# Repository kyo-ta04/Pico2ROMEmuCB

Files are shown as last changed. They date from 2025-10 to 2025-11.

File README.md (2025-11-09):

# Pico2ROMEmu - RP2350B Core Board Version
<!-- ![Pico2ROMEmu RP2350B Core Board](./IMG/Pico2ROMEmuPCB_CoreBoard_img_1.jpg) -->
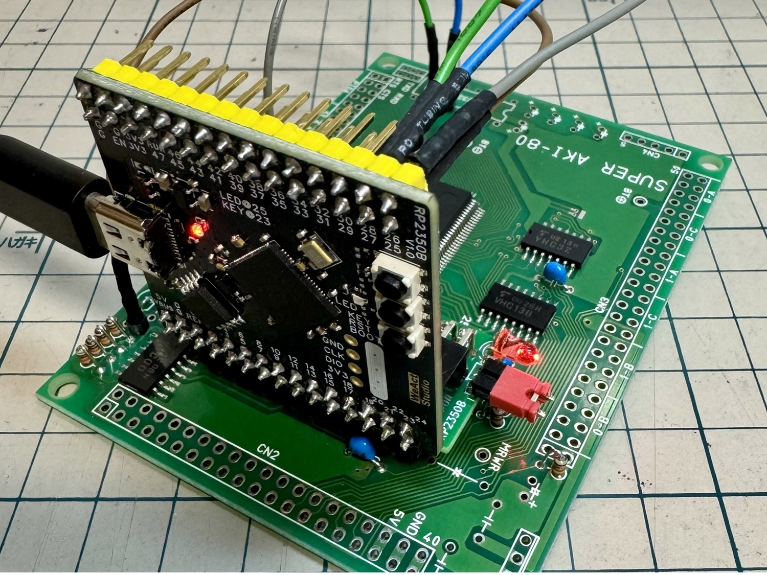
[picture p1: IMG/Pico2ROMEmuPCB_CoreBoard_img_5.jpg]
Pico2ROMEmu RP2350B Core Board

このプロジェクトは Pico2ROMEmuに RP2350B Core Boardを使用した簡単で高速なROMエミュレータです  
[English Readme](./README.en.md)

## 特徴
- 詳しくは[Pico2ROMEmu](https://github.com/kyo-ta04/Pico2ROMEmuBR)をご覧ください。

## 構成
- KiCad 回路図、PCB、ガーバーファイルはこちら→ [./PCB/](./PCB/) (**2025/11/09 追加 V1.0 R0.1**)
  - KiCad Ver9.0.6、 JLCPCB Fabrication Toolkit Plugin 使用
- `saki80mon041_const.c` などの ROMデータ部分は [https://github.com/yyhayami/saki80mon041](https://github.com/yyhayami/saki80mon041) 由来です。  
UNIMON for SAKI80は、asano氏が公開されているUniversal MonitorをベースにAki.H氏による大幅な拡張がなされてEMUZ80用に公開されているEMUZ80_Monitor Rev.B04を @yyhayami氏が Super AKI-80 で動作するよう移植したものです。
- `rom_basic_const.c` などの ROM-BASIC 部分は [saki80basic](https://github.com/vintagechips/saki80basic) 由来です。
  - 元の[BASICサブセット](http://searle.x10host.com/cpm/index.html)は Grant Searle さんが作成したものであり、[Super AKI-80用に @vintagechip（電脳伝説）](https://vintagechips.wordpress.com/2025/04/24/saki80basic/)さんが移植・改良されています。
- [Tom's SBC](https://oshwlab.com/peabody1929/CPM_Z80_Board_REV_B_copy-76313012f79945d3b8b9d3047368abf7)はpeabody1929さんが作成したものであり、ROMデータは[CP/M machine - Grant Searle](http://searle.x10host.com/cpm/index.html) 由来です。
- [68k-nano](https://github.com/74hc595/68k-nano)は Matt Sarnoff(74hc595)さんが作成、公開されています。 ROMデータはソースから生成しました。
- RP2350 PIO ROMエミュレーション部分は @tendai22plus さんの [ROMエミュレーション](https://github.com/tendai22/emuz80_pico2/blob/main/doc/ROM_EMULATION.md) を参考にさせていただいてます。　参考: [emuz80_pico2](https://github.com/tendai22/emuz80_pico2) 
- 使用している WeAct StudioのRP2350B Core Boardは、Raspberry Pi RP2350Bマイクロコントローラを搭載したコンパクトな開発ボードで、サイズわずか41.4×41.1mmながら全48本のI/Oピンを2つの30ピンヘッダー引き出しています。  
Github : [WeActStudio.RP2350BCoreBoard](https://github.com/WeActStudio/WeActStudio.RP2350BCoreBoard)

## 回路図・資料
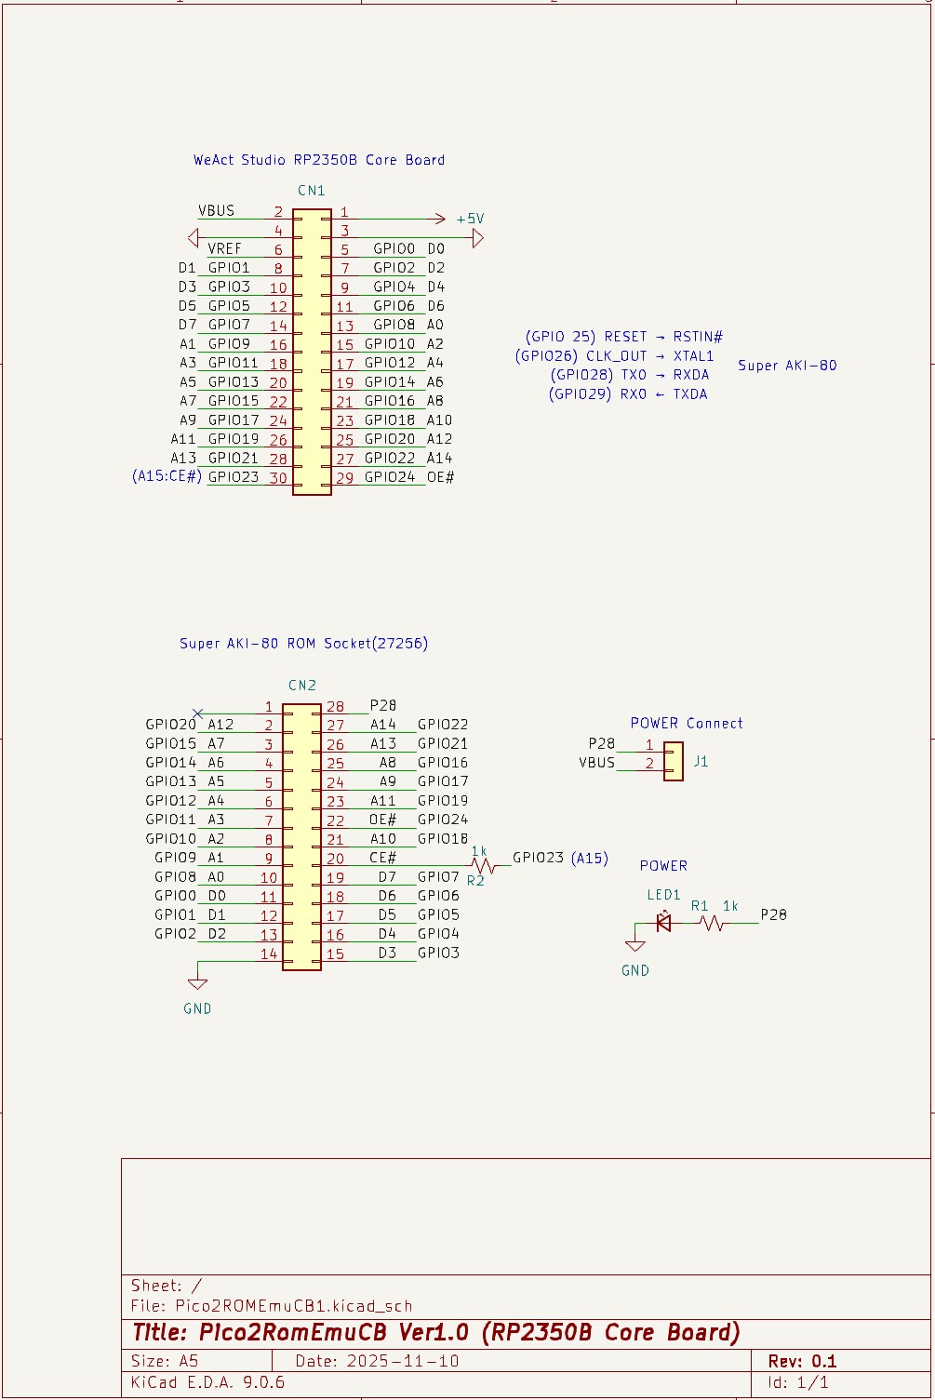
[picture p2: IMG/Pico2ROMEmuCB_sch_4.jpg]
Pico2ROMEmuCB_sch
- 
上記は回路図の画像です。
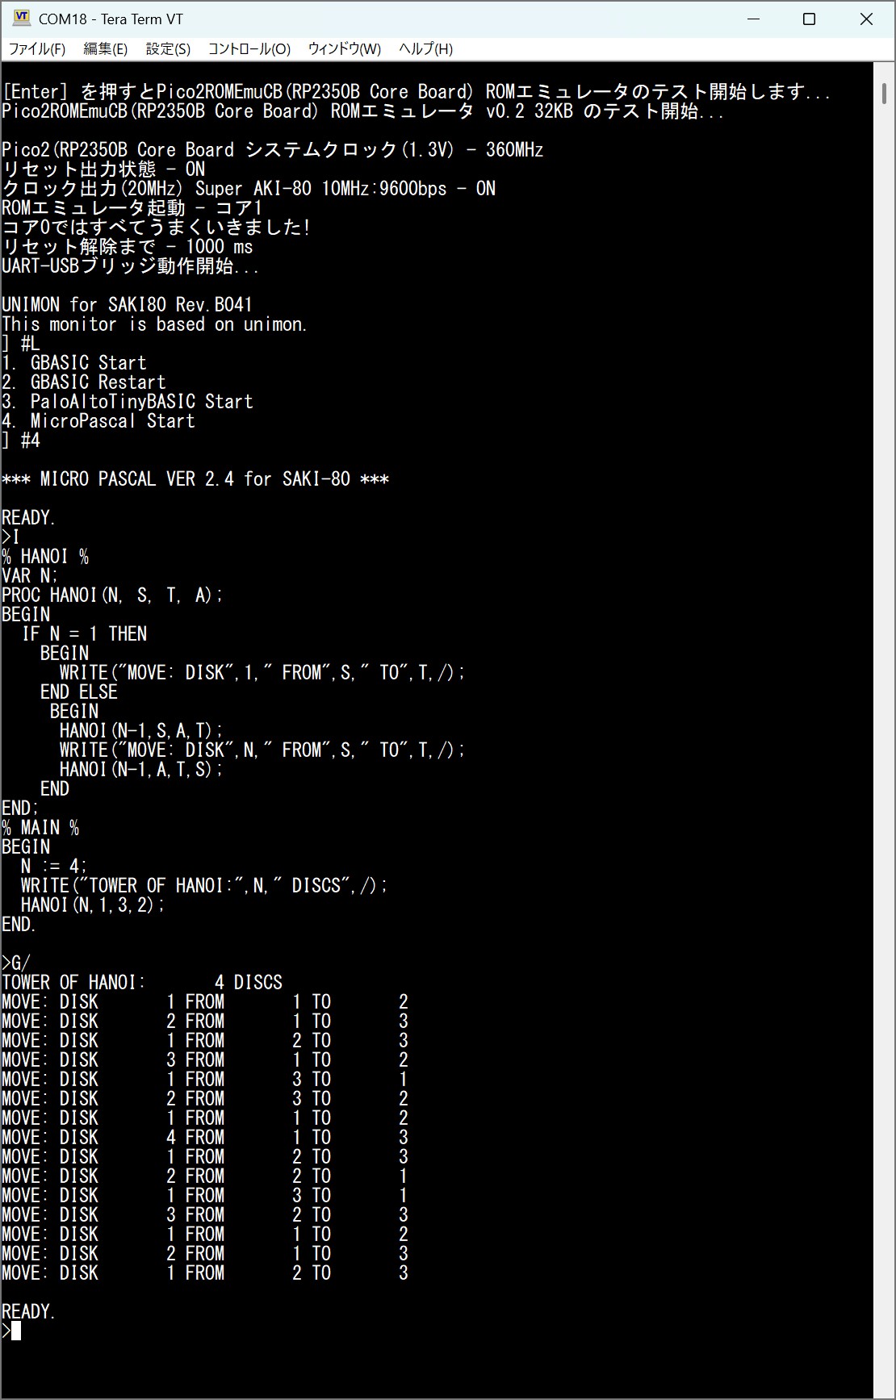
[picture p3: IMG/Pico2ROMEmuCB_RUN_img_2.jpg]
Pico2ROMEmuCB_RUN_img
- 
上記は saki80mon041.hex使用時の実行例画像です。
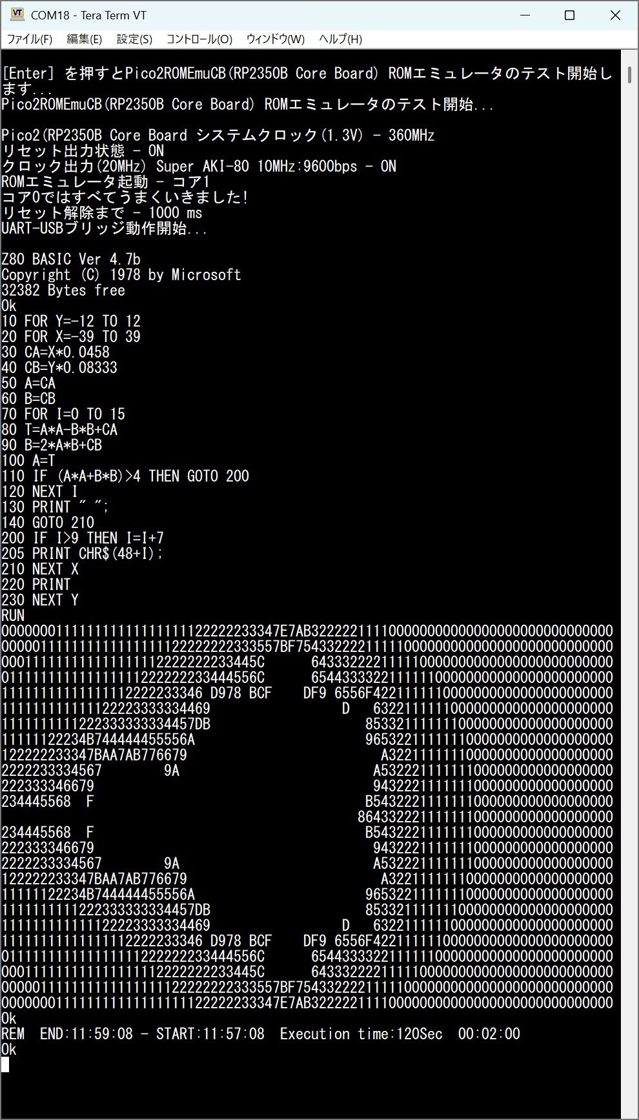
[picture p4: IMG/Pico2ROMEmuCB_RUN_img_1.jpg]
Pico2ROMEmuCB_RUN_img
- 
上記は SAKI80MB.HEX使用時の実行例画像です。

## ライセンス
- 本プロジェクトのソースコードは MIT ライセンスです。
- ROMデータ部分などは元サイトおよび改編元のライセンスを参照してください。

## 免責事項
本ソフトウェアは現状のまま提供されます。いかなる損害についても作者は責任を負いません。

## 謝辞
- Grant Searle さん（[BASICサブセット版/CP/M machine 作者）](http://searle.x10host.com/index.html)）
- @vintagechip さん（[電脳伝説さん Super AKI-80用BASIC 作者](https://vintagechips.wordpress.com/)）
- @tendai22plus さん ([emuz80_pico2  作者](https://github.com/tendai22/emuz80_pico2))
- peabody1929 さん ([Tom's SBC 作者](https://oshwlab.com/peabody1929/works))
- Matt Sarnoff(74hc595)さん ([68k-nano 作者](https://github.com/74hc595/68k-nano))
- @yyhayamiさん（[saki80mon041 作者）](https://github.com/yyhayami/saki80mon041)）
- @electrelic(asano)さん（[Universal Monitor 作者）](https://electrelic.com/electrelic/node/1317)）
- @akih_san(Aki.h) さん（[EMUZ80-MON 作者](https://github.com/akih-san/EMUZ80-MON)）
- @shippoiincho さん、 @kondo_pc88 さん、 @TororoLab さん、 @I_HaL さん、 @antarcticlion さん、 @GAPUX さん、 @Tanuki_Bayashin さん、 @applesorce さん、@W88DodPECuThLOl さんを始めとしたアドバイス、イイね、RPしていただいた皆様。
- Raspberry Pi Pico SDK 開発者の皆様
- 本プロジェクトに関わる全ての方々
- [Pico2ROMEmu](https://github.com/kyo-ta04/Pico2ROMEmuBR)もご覧ください。

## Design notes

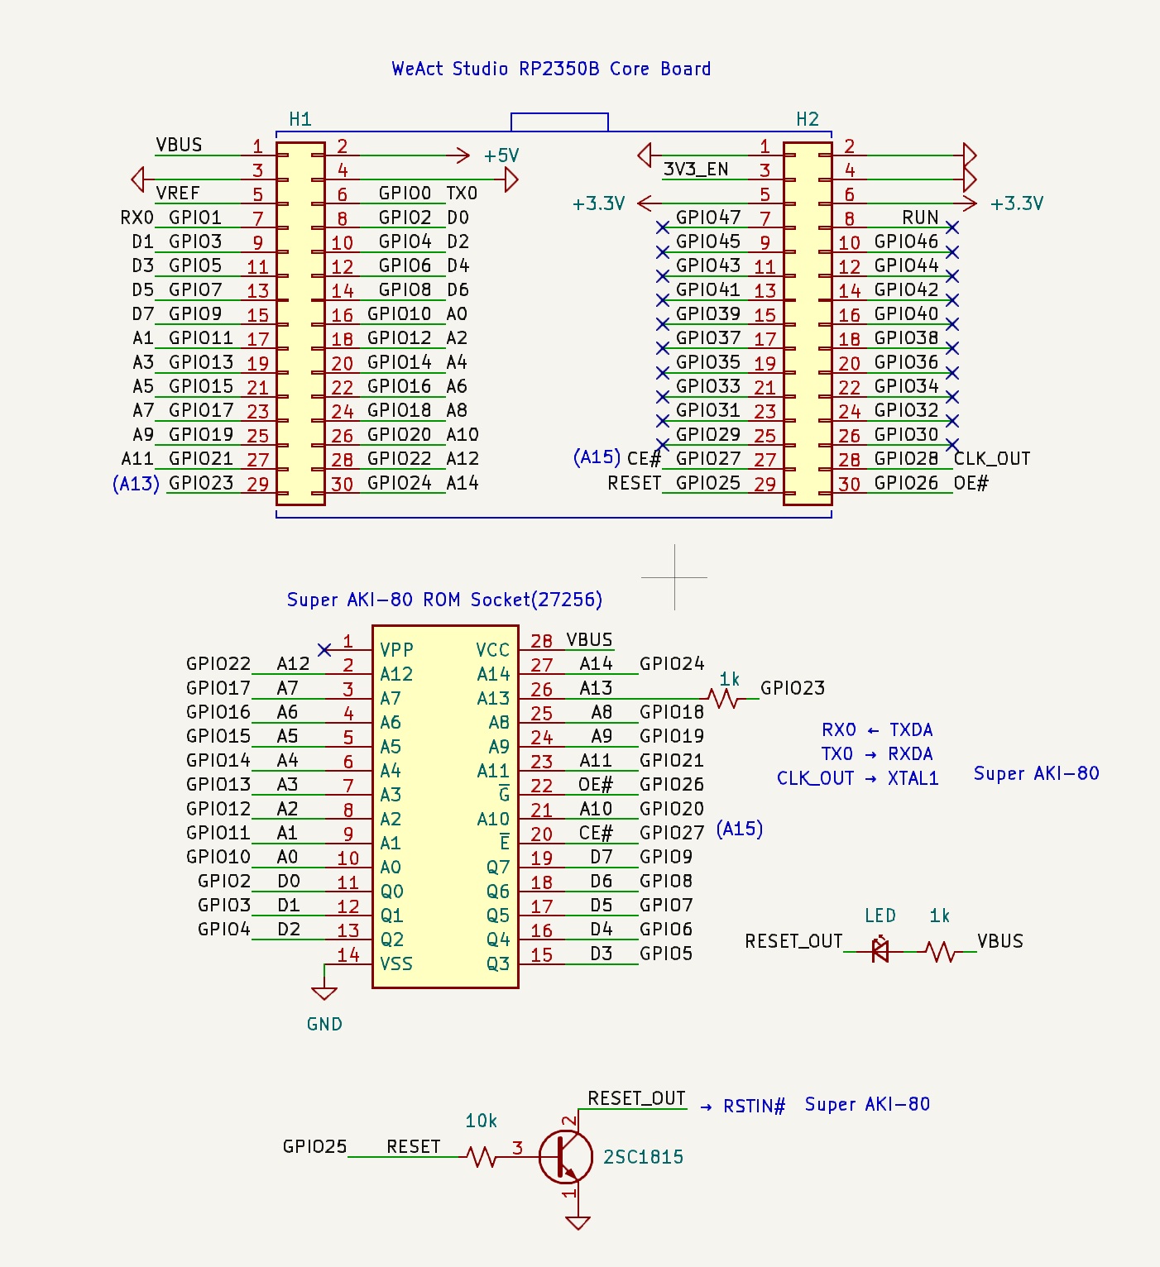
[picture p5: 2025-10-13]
IMG/Pico2ROMEmuCB_sch_2.jpg

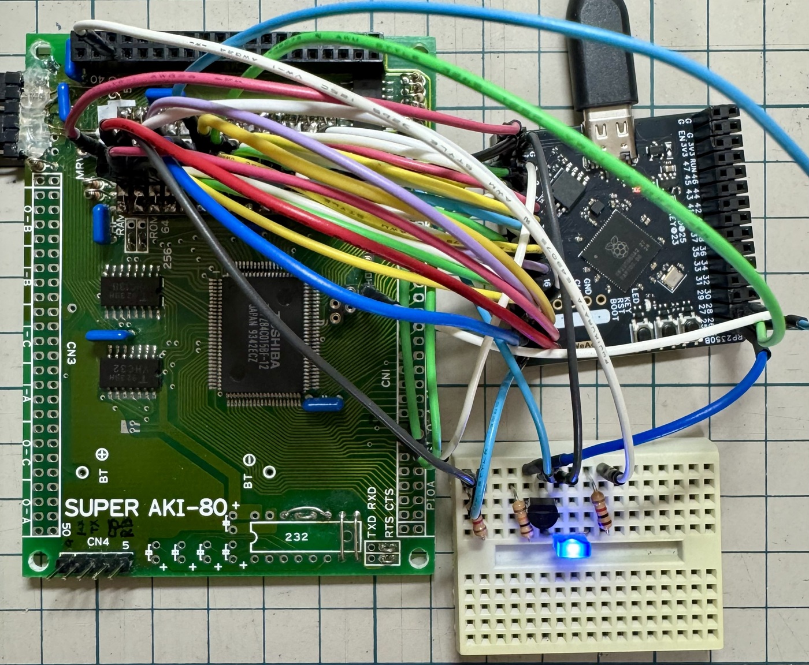
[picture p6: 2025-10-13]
IMG/Pico2ROMEmuPCB_CoreBoard_img_2.jpg

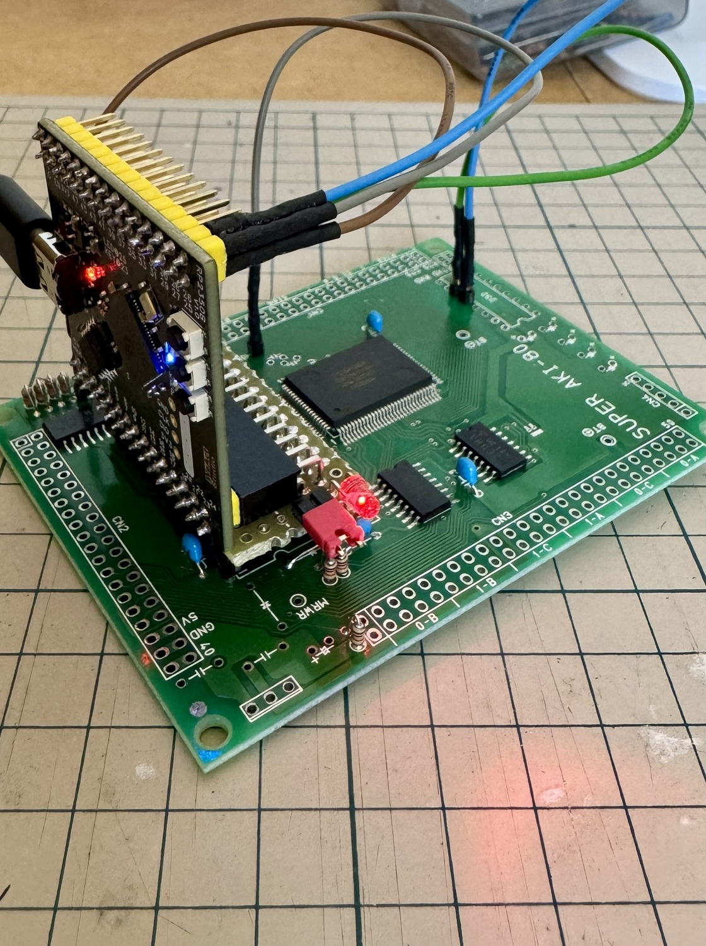
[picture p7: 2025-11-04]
IMG/Pico2ROMEmuPCB_CoreBoard_img_4.jpg

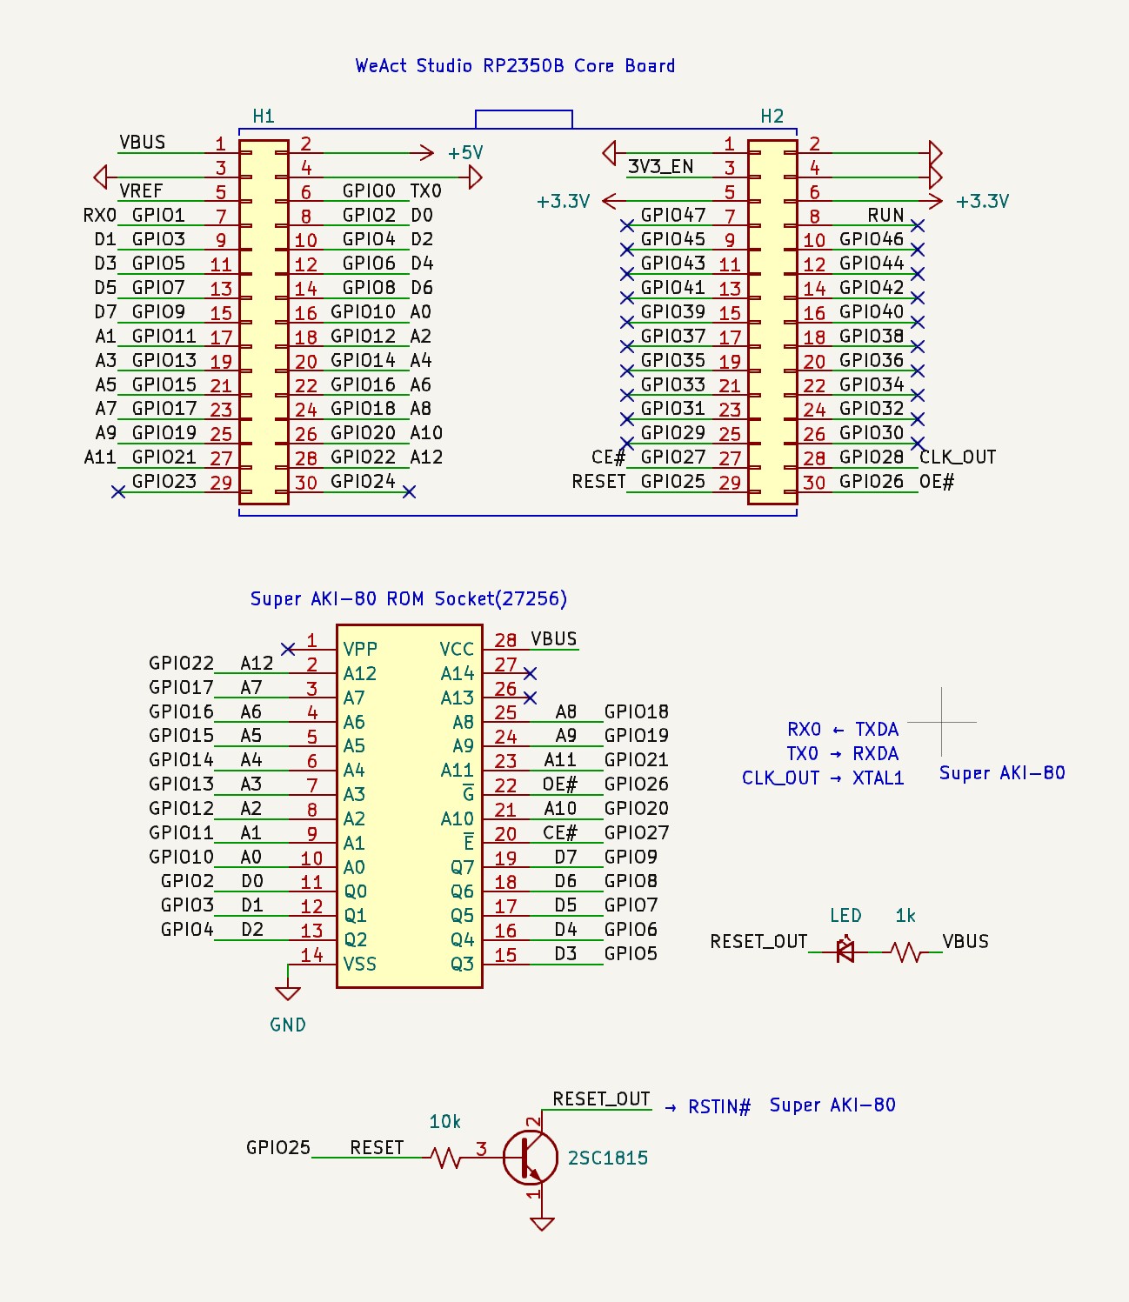
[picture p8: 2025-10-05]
IMG/Pico2ROMEmuCB_sch.jpg

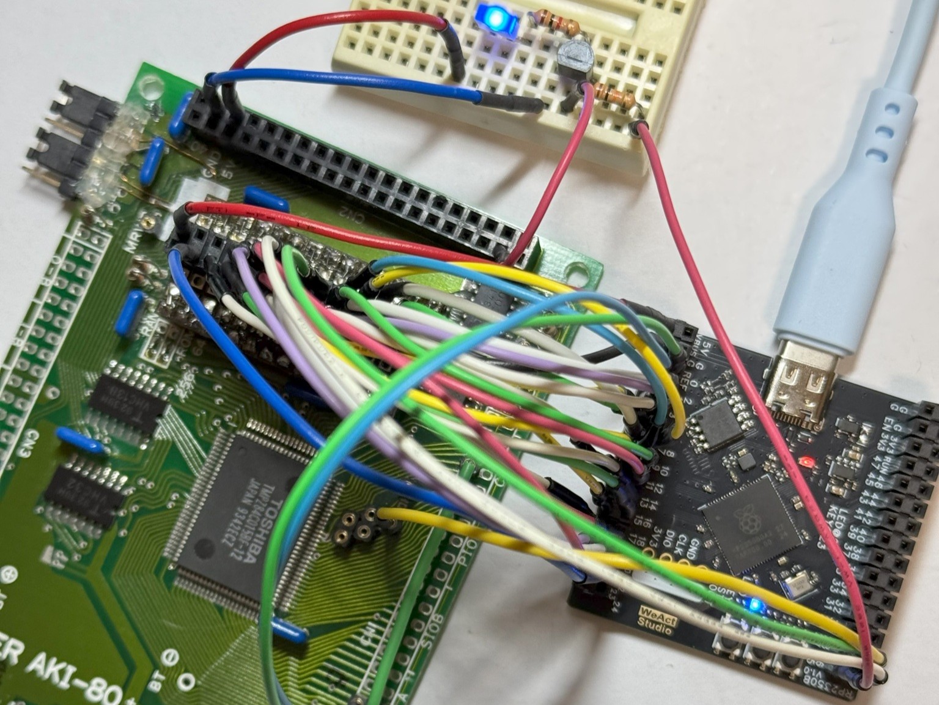
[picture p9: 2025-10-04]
IMG/Pico2ROMEmuPCB_CoreBoard_img_1.jpg

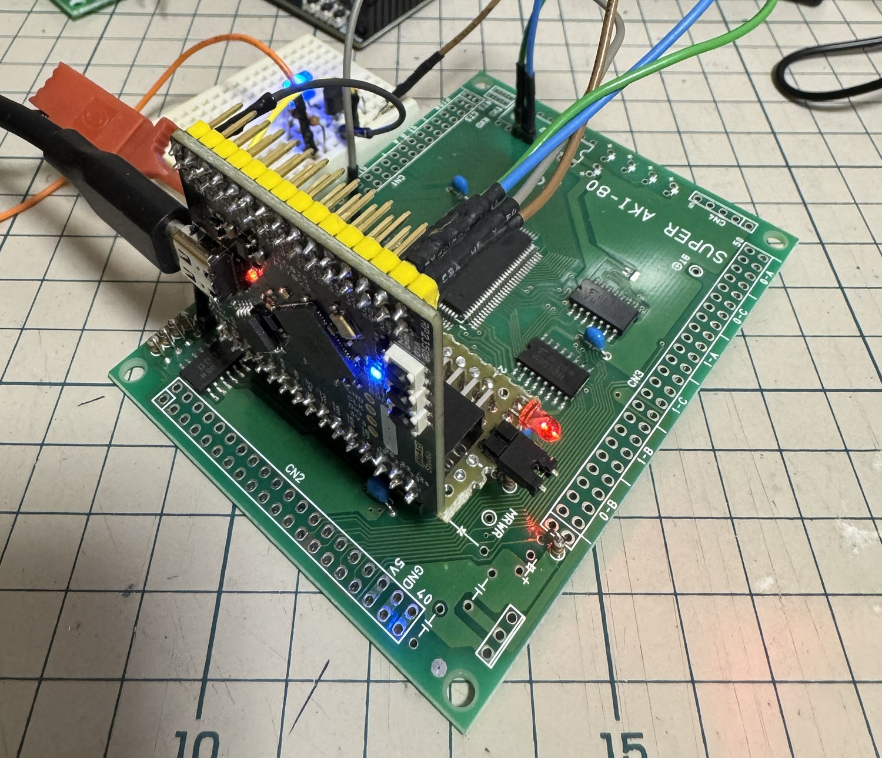
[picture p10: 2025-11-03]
IMG/Pico2ROMEmuPCB_CoreBoard_img_3.jpg

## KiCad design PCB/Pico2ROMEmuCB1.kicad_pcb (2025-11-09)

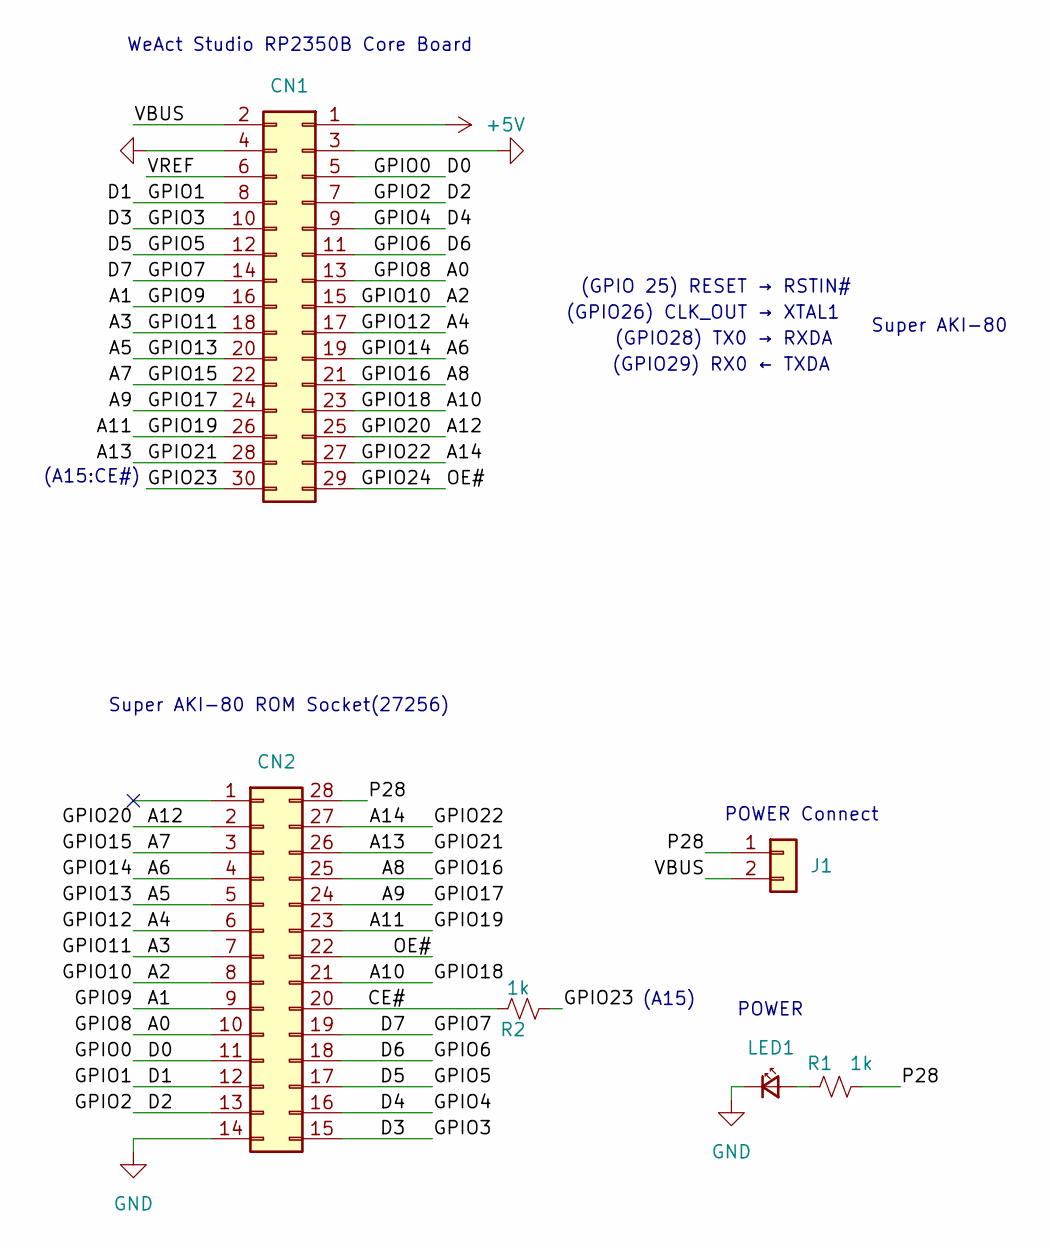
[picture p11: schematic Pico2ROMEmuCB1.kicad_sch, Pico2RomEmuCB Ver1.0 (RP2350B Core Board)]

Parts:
CN1: Conn_02x15; PinSocket_2x15_P2.54mm_Horizontal
CN2: Conn_02x14_Counter_Clockwise; DIP-28_W15.24mm_Socket
J1: Conn_01x02; PinHeader_1x02_P2.54mm_Vertical
LED1: LED_Small; LED_D3.0mm
R1, R2: 1k; R_Axial_DIN0204_L3.6mm_D1.6mm_P5.08mm_Horizontal

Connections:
+5V: CN1.1
/A0: CN1.13, CN2.10
/A1: CN1.16, CN2.9
/A2: CN1.15, CN2.8
/A3: CN1.18, CN2.7
/A4: CN1.17, CN2.6
/A5: CN1.20, CN2.5
/A6: CN1.19, CN2.4
/A7: CN1.22, CN2.3
/A8: CN1.21, CN2.25
/A9: CN1.24, CN2.24
/A10: CN1.23, CN2.21
/A11: CN1.26, CN2.23
/A12: CN1.25, CN2.2
/A13: CN1.28, CN2.26
/A14: CN1.27, CN2.27
/CE#: CN2.20, R2.2
/D0: CN1.5, CN2.11
/D1: CN1.8, CN2.12
/D2: CN1.7, CN2.13
/D3: CN1.10, CN2.15
/D4: CN1.9, CN2.16
/D5: CN1.12, CN2.17
/D6: CN1.11, CN2.18
/D7: CN1.14, CN2.19
/GPIO23: CN1.30, R2.1
/GPIO24: CN1.29, CN2.22
/P28: CN2.28, J1.1, R1.1
/VBUS: CN1.2, J1.2
/VREF: CN1.6
GND: CN1.3, CN1.4, CN2.14, LED1.1 (K)
unnamed: LED1.2 (A), R1.2

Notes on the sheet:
POWER Connect
Super AKI-80
(GPIO28) TX0 → RXDA
WeAct Studio RP2350B Core Board
Super AKI-80 ROM Socket(27256)
POWER
(A15:CE#)
(GPIO26) CLK_OUT → XTAL1
(GPIO 25) RESET → RSTIN#
(GPIO29) RX0 ← TXDA
(A15)

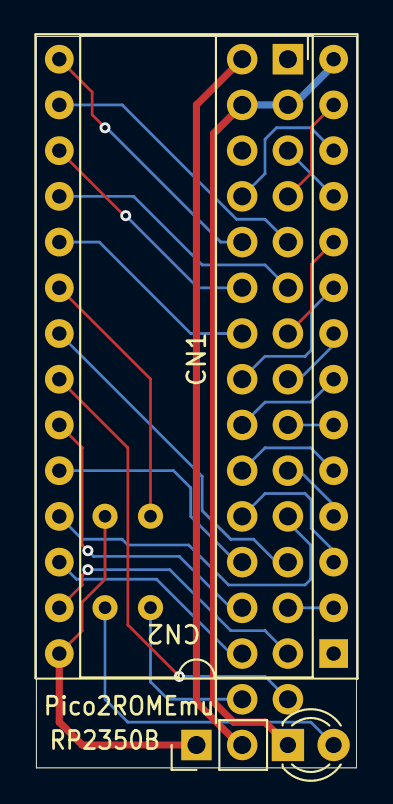
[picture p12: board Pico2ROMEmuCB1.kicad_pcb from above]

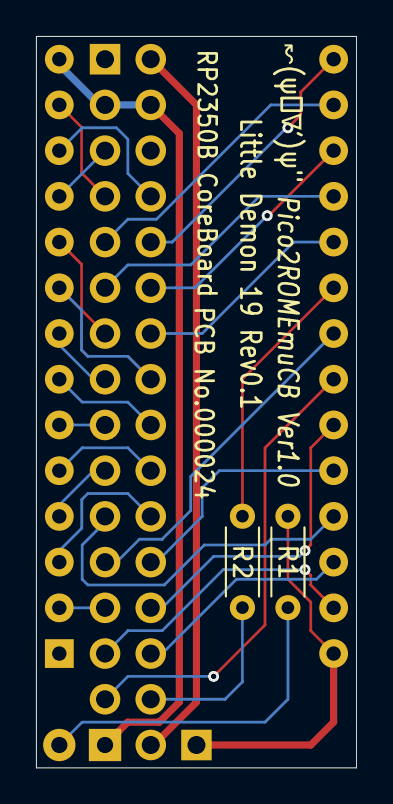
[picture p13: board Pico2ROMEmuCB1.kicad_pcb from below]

Board: 2 copper layers, 17.8 x 40.6 mm, 6 parts (2 on the bottom side), 30 nets.

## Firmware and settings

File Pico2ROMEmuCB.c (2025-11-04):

//
// Pico2ROMEmuCB.c - Pico2ROMEmuCB(RP2350B Core Board) 用 ROMエミュレータ
// 2024/06/15 by @DragonballEZ(kyo-ta04)
//
#include <stdio.h>
#include <string.h>
#include "pico/stdlib.h"
#include "hardware/vreg.h"
#include "hardware/pio.h"
#include "hardware/clocks.h"
#include "hardware/uart.h"
#include "hardware/pll.h"
#include "pico/multicore.h"
#include "rom_emu.pio.h"
// #include "rom_basic_const.c" 
#include "saki80mon041_const.c" 

#define DATA_PINS_BASE 0    // GP0～GP7 (D0-D7 8bit)
#define ADDR_PINS_BASE 8    // GP8～GP22 (A0-A14 15bit)
#define CS_PIN 23           // GP23 Chip Select (CS#:A15)
#define OE_PIN 24           // GP24 Output Enable (OE#)
#define RESETOUT_PIN 25     // GP25 (リセット出力)

#define CLKOUT_PIN 26       // GP26 (クロック出力)

// UART0の設定
#define UART_ID uart0
#define UART_TX_PIN 28
#define UART_RX_PIN 29
#define BAUD_RATE 9600

#define FLAG_VALUE 123

#define ROM_SIZE 32768 // 32Kバイト (15bitアドレス)

// PIO初期化
PIO pio = pio0;
uint sm = 0;


uint8_t rom_data[ROM_SIZE] __attribute__((section(".data")));

// コア1のエントリポイント
// core1_entry()はPIOの状態マシンを実行し、ROMデータを送信する  
__attribute__((noinline)) void __time_critical_func(core1_entry)(void) {
    multicore_fifo_push_blocking(FLAG_VALUE);
    uint32_t g = multicore_fifo_pop_blocking();
    while (true) {
        uint32_t address = pio_sm_get_blocking(pio, sm);    // アドレスを取得
        uint32_t data = rom_data[address];                  // 13bitアドレスに対応
        pio_sm_put(pio, sm, data);                          // データを送信
    }
}


// rom_saki80mon041[]をrom_data[]にコピーする初期化ルーチン
void init_rom_basic_code(void) {
    // rom_saki80mon041[]の内容をrom_data[]の先頭にコピー
    memcpy(rom_data, rom_saki80mon041, sizeof(rom_saki80mon041));
    // 残りのrom_data[]を0xFFで埋める（32Kバイトまで）
    memset(rom_data + sizeof(rom_saki80mon041), 0xFF, ROM_SIZE - sizeof(rom_saki80mon041));
}


// QSPIクロックを調整する関数
void set_qspi_clock_divider(uint32_t sys_clock_khz, uint32_t qspi_max_khz) {
    uint32_t divider = (sys_clock_khz + qspi_max_khz - 1) / qspi_max_khz;
    clock_configure(clk_peri, 0, CLOCKS_CLK_PERI_CTRL_AUXSRC_VALUE_CLKSRC_PLL_SYS, sys_clock_khz * 1000, sys_clock_khz * 1000 / divider);
}

__attribute__((noinline)) int __time_critical_func(main)(void) {
    uint32_t sysclk = 360 * 1000;           // Pico2 システムクロック 280/320/360MHz 
    vreg_set_voltage(VREG_VOLTAGE_1_30);    // 電圧を1.3Vに設定
    sleep_ms(100);                          // 電圧安定のための待機
    set_sys_clock_khz(sysclk, true);        // 高速動作
    set_qspi_clock_divider(sysclk, 133000); // QSPIクロックを133MHz以下に

    stdio_init_all();
    setbuf(stdout, NULL);           // 標準出力のバッファリングを無効化 

    // UART0の初期化
    uart_init(UART_ID, BAUD_RATE);
    // UARTピンの設定（GPIO0=TX, GPIO1=RX）
    gpio_set_function(UART_TX_PIN, GPIO_FUNC_UART);
    gpio_set_function(UART_RX_PIN, GPIO_FUNC_UART);

    // PIO初期化
    uint offset = pio_add_program(pio, &oe_address_control_program);
    pio_sm_config c = oe_address_control_program_get_default_config(offset);

    uint sm1 = 1; // sm1を使用
    uint offset1 = pio_add_program(pio, &clk_out_program);
    pio_sm_config c1 = clk_out_program_get_default_config(offset1);
 
    uint sm2 = 2; // sm2を使用
    // sm2 のリセット出力プログラムをロード
    uint offset2 = pio_add_program(pio, &reset_out_program);
//    pio_sm_config c2 = reset_out_program_get_default_config(offset2);
 
    // GP0-7：出力
    for (int i = 0; i < 8; i++) {
        pio_gpio_init(pio, DATA_PINS_BASE + i);
    }
    // GP8-22：入力(15ピン A0-A14)
    for (int i = 0; i < 15; i++) {
        pio_gpio_init(pio, ADDR_PINS_BASE + i);
    }
    
    pio_gpio_init(pio, RESETOUT_PIN); // リセット出力ピン(GP25)の初期化
    pio_gpio_init(pio, OE_PIN); // OEピン(GP24)の初期化
    pio_gpio_init(pio, CS_PIN); // CSピン(GP23)の初期化
    pio_gpio_init(pio, CLKOUT_PIN); // CLK出力ピン(GP26)の初期化

    sm_config_set_in_pins(&c, ADDR_PINS_BASE);
    sm_config_set_out_pins(&c, DATA_PINS_BASE, 8);
    sm_config_set_jmp_pin(&c, OE_PIN); // GPIO24 OEをJMPピンとして設定
    

    pio_sm_set_consecutive_pindirs(pio, sm, DATA_PINS_BASE, 8, false); // 出力ピン初期化

    // シフトレジスタの設定
    sm_config_set_in_shift(&c, false, false, 0); // ISR（入力シフトレジスタ）のシフト方向
    sm_config_set_out_shift(&c, true, false, 0); // OSR（出力シフトレジスタ）のシフト方向

    // sm1 のクロック出力を設定 
    sm_config_set_set_pins(&c1, CLKOUT_PIN, 1); // GP26をクロック出力ピンとして設定
    pio_sm_set_consecutive_pindirs(pio, sm1, CLKOUT_PIN, 1, true); // CLKOUTピンの初期化

    float clkout_freq = 20000.0f; // kHz - 20MHz (Super Aki-80 10MHz 9600bps)
    sm_config_set_clkdiv(&c1, (float)sysclk / (2.0f * clkout_freq)); // クロック出力のクロック設定

     // sm2 のリセット出力を設定
    // Set initial pin direction to INPUT (false) for Hi-Z state at startup.
    pio_sm_set_consecutive_pindirs(pio, sm2, RESETOUT_PIN, 1, false); // リセット出力ピンの初期化(Hi-z:入力に設定) 
    pio_sm_config c2 = reset_out_program_get_default_config(offset2);
    sm_config_set_set_pins(&c2, RESETOUT_PIN, 1); // GP25をリセット出力ピンとして設定 ??????
    sm_config_set_clkdiv(&c2, sysclk / 10); //  10kHz (リセット出力のクロック)
    pio_sm_init(pio, sm2, offset2, &c2);
    pio_sm_set_enabled(pio, sm2, true);

    // sm のROMエミュプログラムをロード
    pio_sm_init(pio, sm, offset, &c);
    pio_sm_set_enabled(pio, sm, true);

    sleep_ms(1); // 1ms待機

    // sm1 のクロック出力プログラムをロード
    pio_sm_init(pio, sm1, offset1, &c1);
    pio_sm_set_enabled(pio, sm1, true);
    init_rom_basic_code(); // rom_basic_const.cから初期化
    sleep_ms(3000); // 3秒待機
    // [Enter]入力を待つ
    printf("\n[Enter] を押すとPico2ROMEmuCB(RP2350B Core Board) ROMエミュレータのテスト開始します...\n");
    while (true) {
        int c = getchar_timeout_us(100000); // 100msタイムアウト
        if (c == '\r') { // [Enter]（CR）が入力されたら開始
            printf("Pico2ROMEmuCB(RP2350B Core Board) ROMエミュレータ v0.2 32KB のテスト開始...\n");
            break;
        }
    }
    printf("\nPico2(RP2350B Core Board) システムクロック(1.3V) - %dMHz\n", sysclk / 1000);
    printf("リセット出力状態 - ON\n");
    printf("クロック出力(%dMHz) Super AKI-80 %dMHz:%dbps - ON\n", (int)(clkout_freq / 1000),(int)(clkout_freq / 2000), BAUD_RATE);
    printf("ROMエミュレータ起動 - コア1\n");
    multicore_launch_core1(core1_entry);
    uint32_t g = multicore_fifo_pop_blocking();
    if (g != FLAG_VALUE)
        printf("うーん、コア0では正しくありません!\n");
    else {
        multicore_fifo_push_blocking(FLAG_VALUE);
        printf("コア0ではすべてうまくいきました!\n");
    }

    uint32_t tim = 1000; 
    printf("リセット解除まで - %d ms\n", tim);
    pio_sm_put(pio, sm2, tim);

    // メインループ
    printf("UART-USBブリッジ動作開始...\n");

    while (true) {
        // UARTの受信データがあるかチェック
        if (uart_is_readable(UART_ID)) {
            int c = uart_getc(UART_ID);     // UARTから1文字受信
            putchar_raw(c);                 // 受信データをそのままUSBへ送信
        }
        // USBから受信データがあるかチェック
        int c;
        if ((c = getchar_timeout_us(0)) != PICO_ERROR_TIMEOUT) {
            uart_putc_raw(UART_ID, c); // UARTへデータ送信
        }
    }
    return 0;
}

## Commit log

2025-10-05 回路図の差替え
2025-10-06 開始メッセージ修正
2025-10-06 READMEに実行例追加
2025-10-06 画像差替え
2025-10-13 A13,14追加、コメント修正
2025-10-13 rom_saki80mon041に変更
2025-10-13 README.md修正、画像変更
2025-10-13 README.en.md修正
2025-10-13 README修正
2025-11-02 CB1 PCB
2025-11-04 Change RESET to pseudo-open-drain output.
    [Pico2ROMEmuCB.c]
2025-11-09 PCB ADD
    [Pico2ROMEmuCB1.kicad_pcb, Pico2ROMEmuCB1.kicad_sch]
2025-11-10 uf2 入替え
2025-11-10 回路素 修正
    [Pico2ROMEmuCB1.kicad_sch]
2025-12-20 不要ファイル削除
